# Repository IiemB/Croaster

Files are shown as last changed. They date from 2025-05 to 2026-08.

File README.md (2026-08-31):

# ☕ Croaster - Open Source Coffee Roaster Monitor

> 🇮🇩 Versi Bahasa Indonesia tersedia di [README_ID.md](README_ID.md)

**Croaster** is a lightweight, open-source temperature monitoring system built on ESP-based microcontrollers. Designed for coffee roasting enthusiasts and professionals, it reads from two thermocouple sensors (Bean Temperature and Environment Temperature) and displays real-time data on a compact OLED screen. Croaster connects seamlessly to popular roasting software via WiFi (WebSocket) and BLE (on boards that support it), making it compatible with both desktop and mobile roasting apps.

**Current Firmware Version:** `0.52`

---

## 📑 Table of Contents

- [☕ Croaster - Open Source Coffee Roaster Monitor](#-croaster---open-source-coffee-roaster-monitor)
  - [📑 Table of Contents](#-table-of-contents)
  - [🚀 Features](#-features)
  - [🧩 Hardware Components](#-hardware-components)
  - [🛠 Software Architecture](#-software-architecture)
    - [Data Flow](#data-flow)
  - [📦 Libraries \& Dependencies](#-libraries--dependencies)
  - [🔧 How to Build and Upload](#-how-to-build-and-upload)
  - [📦 Using Croaster as a library in your own project](#-using-croaster-as-a-library-in-your-own-project)
  - [🔗 WiFi Setup Guide](#-wifi-setup-guide)
  - [📡 Communication Overview](#-communication-overview)
    - [WebSocket (WiFi)](#websocket-wifi)
    - [BLE](#ble)
  - [🔌 How to Connect Croaster with Artisan](#-how-to-connect-croaster-with-artisan)
    - [🖥️ Option 1: Direct Connection (Croaster as Access Point)](#️-option-1-direct-connection-croaster-as-access-point)
    - [🌐 Option 2: Same WiFi Network (Croaster joins your WiFi)](#-option-2-same-wifi-network-croaster-joins-your-wifi)
  - [⬆️ OTA (Over-The-Air) Updates](#️-ota-over-the-air-updates)
  - [🧪 Custom Commands](#-custom-commands)
    - [Built-in Commands](#built-in-commands)
    - [Adding Custom Commands](#adding-custom-commands)
  - [📘 License](#-license)
  - [❤️ Contributing](#️-contributing)
  - [🔗 Related Links](#-related-links)

---

## 🚀 Features

* Supports **ESP8266 and ESP32** based boards via per-board implementations
* Real-time monitoring of **two MAX6675 thermocouple sensors**:
  - **BT** — Bean Temperature (inside the drum)
  - **ET** — Environment Temperature (exhaust/inlet)
* **Rate of Rise (RoR)** calculation for both BT and ET, updated automatically
* Temperature unit switching: **Celsius** or **Fahrenheit**
* Configurable data send interval (default: every **3 seconds**)
* Built-in **temperature smoothing** (smoothing factor: 5) to reduce sensor noise
* Visual output on a **128×64 OLED display** (SSD1306, I2C)
* WiFi communication via **WebSocket** on port **81**, compatible with:
  + [**Artisan Roaster Scope**](https://artisan-scope.org/) — industry-standard roasting logger
  + [**ICRM app**](https://iiemb.github.io/#/icrm) — companion mobile app (Android)
* **BLE communication** (on boards that support it) for the [**ICRM app**](https://iiemb.github.io/#/icrm)
* **OTA (Over-The-Air) firmware updates** via WebSocket (WiFi) and **BLE** (on boards that support it)
* **WiFiManager** captive portal for easy WiFi credential setup — no re-flashing needed
* Unique device naming based on chip ID (e.g. `Croaster-A1B2`)
* **Dummy mode** for development and testing without physical sensors
* Custom JSON command system via the centralized `CroasterCommandHandler` class
* Easily extendable with user-defined commands

---

## 🧩 Hardware Components

| Component | Description |
|:---|:---|
| 1× ESP-based microcontroller (WiFi and/or BLE) | Main microcontroller — see `boards/<board>/README.md` for the supported boards |
| 1× [128×64 OLED display (SSD1306, I2C)](images/OLED-Display.png) | Real-time temperature display |
| 2× [MAX6675 thermocouple modules](images/MAX6675.png) | SPI-based K-type thermocouple ADC |
| 2× [K-type thermocouple probes](images/Type-K-thermocouple.png) | Temperature probes (BT & ET) |

> All components run on **3.3V**. Ensure your power supply can handle the combined current draw of both sensors and the display.

> 🔌 **Wiring diagrams are per board** — see `boards/<board>/README.md`.

---

## 🛠 Software Architecture

Croaster uses a clean, **modular C++ architecture** built with the Arduino framework. Each subsystem is encapsulated in its own class.

The repository is structured as a **reusable library** (`croaster/`: `croaster/src/` + `croaster/library.json`) plus per-board **projects** in `boards/<board>/`. The library is **display- and pin-config-agnostic** — each board supplies its own display, pin layout, LED and dummy-mode configuration.

### Library modules (`croaster/src/`)

| Module | File | Responsibility |
|:---|:---|:---|
| `CroasterCore` | `croaster/src/CroasterCore.h/.cpp` | Sensor reading, RoR calculation, temperature smoothing, data state |
| `CroasterDisplay` | `croaster/src/CroasterDisplay.h` | **Abstract display interface** — implemented by the consuming project |
| `CroasterPinConfig` | `croaster/src/CroasterPinConfig.h` | Thermocouple pin layout (passed to `CroasterCore`) |
| `CroasterCommandHandler` | `croaster/src/CroasterCommandHandler.h/.cpp` | JSON command parsing and dispatching (BLE & WebSocket) |
| `CroasterWebSocketManager` | `croaster/src/CroasterWebSocketManager.h/.cpp` | WebSocket server, data broadcast, OTA trigger |
| `CroasterBleManager` | `croaster/src/CroasterBleManager.h/.cpp` | BLE server, characteristic notify, command receive *(only compiled when the board has BLE)* |
| `CroasterOtaHandler` | `croaster/src/CroasterOtaHandler.h/.cpp` | Binary OTA update handling over WebSocket and BLE |
| `CroasterWiFiManager` | `croaster/src/CroasterWiFiManager.h/.cpp` | WiFiManager captive portal setup and lifecycle |
| `CroasterDeviceIdentity` | `croaster/src/CroasterDeviceIdentity.h/.cpp` | Chip ID, device name, IP address helpers |
| `CroasterApp` | `croaster/src/CroasterApp.h/.cpp` | **Single `begin()`/`loop()` entry point** — display-agnostic; takes `CroasterCore&` + `CroasterDisplay*` (+ LED pin/level) |

### Board projects (`boards/`)

Shared components and per-board projects live under `boards/`:

| Path | Purpose |
|:---|:---|
| `boards/common/` | Shared SSD1306 display + animation (`CroasterDisplaySSD1306`, `CroasterDisplayAnimation`) used by the OLED-based boards |
| `boards/<board>/` | Per-board project: `platformio.ini`, `main.cpp`, `config.h`, plus a `README.md` documenting that board (wiring, build flags, partitions) |

Each board folder is a standalone PlatformIO project (`main.cpp` + `config.h`) that consumes the Croaster library (`../../croaster`) and any shared components (`../common`), then wires them into the library's display-agnostic `CroasterApp`.

### Data Flow

```
MAX6675 Sensors → CroasterCore (read + smooth + RoR)
                       ↓
          ┌────────────┴────────────┐
  CroasterWebSocketManager  CroasterBleManager (boards with BLE)
          ↓                         ↓
   Artisan / ICRM              ICRM (Android)
```

---

## 📦 Libraries & Dependencies

| Library | Purpose |
|:---|:---|
| [arduinoWebSockets](https://github.com/Links2004/arduinoWebSockets) | WebSocket server |
| [ArduinoJson](https://arduinojson.org/) `^7.4.3` | JSON command parsing and serialization |
| [Adafruit SSD1306](https://github.com/adafruit/Adafruit_SSD1306) `^2.5.16` | OLED display driver |
| [MAX6675_Thermocouple](https://github.com/YuriiSalimov/MAX6675_Thermocouple) `^2.0.2` | Thermocouple sensor reading |
| [WiFiManager](https://github.com/tzapu/WiFiManager) `^2.0.17` | Captive portal WiFi setup |
| ESP32 BLE Arduino *(built-in ESP32 core)* | BLE server & characteristics |

---

## 🔧 How to Build and Upload

> PlatformIO is the only supported workflow (Arduino IDE is not used).

The library lives in `croaster/`. Each supported board has its own folder under
`boards/` — pick it and build/upload from there:

1. Install [PlatformIO](https://platformio.org/) (VS Code extension or CLI)
2. Clone the repository and enter your board's folder:

   ```bash
   git clone git@github.com:IiemB/Croaster.git
   cd Croaster/boards/<board>
   ```

3. Review `platformio.ini` and select your target environment
4. Upload the firmware:

   ```bash
   pio run -t upload
   ```

Each board's `README.md` documents its own build command, wiring and any special
build flags (e.g. custom partition tables).

---

## 📦 Using Croaster as a library in your own project

`croaster/` is a standard PlatformIO library (it ships its own `library.json`).
Add it to another project's `platformio.ini`:

```ini
[env:your_board]
lib_deps =
    https://github.com/IiemB/Croaster.git
```

The easiest way to start is to copy a board (`boards/<board>/`) and adapt it.
It exposes a single `begin()`/`loop()`
API via `CroasterApp`, and all board-specific config (pins, dummy mode, LED,
display) lives in the implementation — not the library:

```cpp
#include <Arduino.h>
#include <ArduinoJson.h>
#include "config.h"                 // pins, dummyMode, ledPin/ledOnLevel (edit here)
#include "CroasterDisplaySSD1306.h" // or your own CroasterDisplay subclass
#include "CroasterApp.h"

CroasterCore core(dummyMode, pins);
CroasterDisplaySSD1306 display(core);     // display defined in the implementation
CroasterApp app(core, &display, ledPin, ledOnLevel);

void setup() { app.begin(); }
void loop()  { app.loop(); }
```

Or wire it yourself (see `CroasterApp.cpp` for the full wiring):

```cpp
#include <CroasterCore.h>
#include <CroasterPinConfig.h>
#include <CroasterCommandHandler.h>
#include <CroasterWebSocketManager.h>
#include <CroasterBleManager.h>
#include <CroasterWiFiManager.h>

CroasterPinConfig myPins = { /* sckPin, soPin, csPinBt, csPinEt */ };

CroasterCore croaster(false, myPins);   // your pin layout
MyDisplay display(croaster);            // your CroasterDisplay subclass
CroasterCommandHandler commands(croaster, &display);
CroasterWebSocketManager ws(croaster, commands, &display);

#if CROASTER_HAS_BLE  // auto-detected: 1 on ESP32, 0 otherwise
CroasterBleManager ble(croaster, commands, &display);
#endif
```

- **Display** — implement `CroasterDisplay` (`begin`, `loop`, `rotateScreen`,
  `blinkIndicator`, `displayToggle`, and the OTA-progress methods). Pass
  `nullptr` where the board has no display.
- **Pins, dummy mode & LED** — build your own `CroasterPinConfig` and pass it
  to `CroasterCore`; choose `dummyMode`, `ledPin`/`ledOnLevel` in the
  implementation's `config.h`.
- **BLE** — the library detects BLE support at compile time via
  `CROASTER_HAS_BLE` (1 on ESP32, 0 elsewhere) and only compiles
  `CroasterBleManager` when available.
- **Custom commands** — add commands without touching the library:
  `app.commands().onCommand("ping", ...)` for string commands and
  `app.commands().onJsonCommand("myKey", ...)` for nested JSON commands.

---

## 🔗 WiFi Setup Guide

Croaster uses **WiFiManager** to handle WiFi credentials without re-flashing. On first boot (or after erasing credentials), Croaster creates its own access point:

1. On your phone or computer, connect to the WiFi network named `[XXXX] Croaster-XXXX`
2. A captive portal will open automatically — enter your home WiFi SSID and password
3. Croaster will save the credentials and connect automatically on subsequent boots
4. The IP address assigned to Croaster is shown on the OLED display

For a visual walkthrough, see: ➡️ [How to Connect to WiFi - YouTube](https://www.youtube.com/watch?v=esNiudoCEcU&t=434s)

---

## 📡 Communication Overview

### WebSocket (WiFi)

- **Port:** `81`
- **Protocol:** WebSocket (text frames for JSON commands, binary frames for OTA)
- **Data format:** JSON, broadcast every `intervalSend` seconds (default: 3s)
- Compatible with **Artisan Roaster Scope** and **ICRM app** (Android)

### BLE

- **Service UUID:** `1cc9b045-a6e9-4bd5-b874-07d4f2d57843`
- **Data Characteristic UUID:** `d56d0059-ad65-43f3-b971-431d48f89a69`
- Supports notify (data push) and write (command receive)
- Available on boards that support BLE (e.g. ESP32) — compatible with the **ICRM app** (Android)

---

## 🔌 How to Connect Croaster with Artisan

You can connect your Croaster device to Artisan using either a direct WiFi connection or through your home/local WiFi network.

1. Open Artisan → **Config → Device**
2. Select **Meter → WebSocket**
   
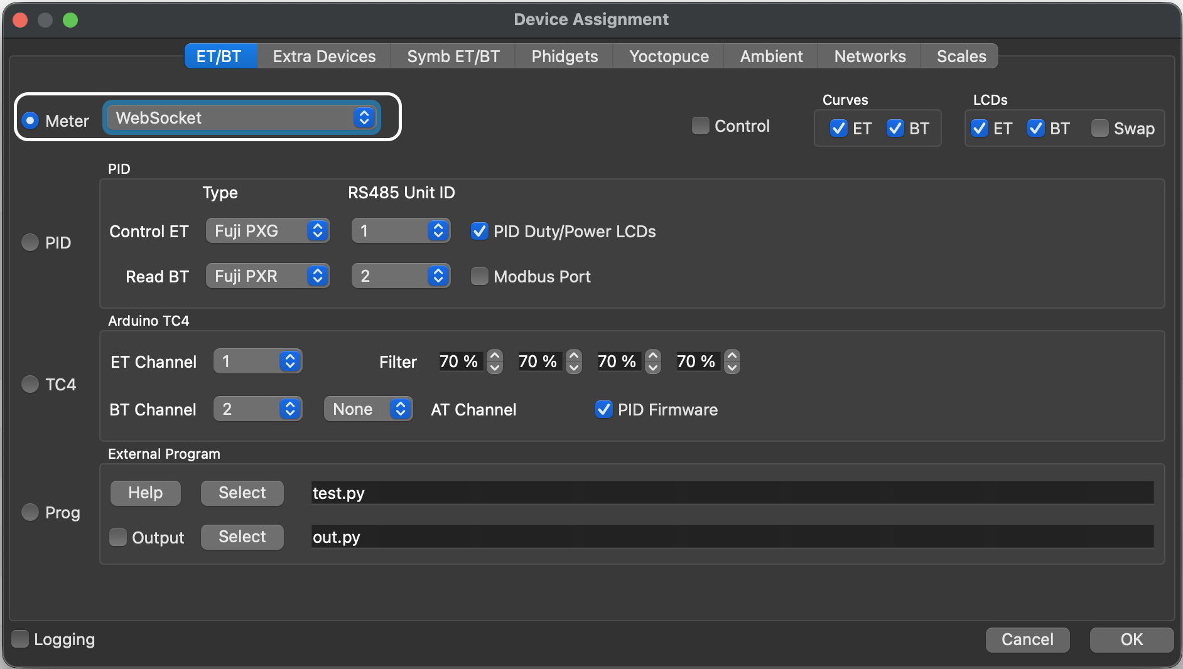
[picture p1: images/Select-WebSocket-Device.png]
   

### 🖥️ Option 1: Direct Connection (Croaster as Access Point)

Use this method when Croaster is **not** connected to any WiFi network, or when you want a direct peer-to-peer connection.

1. On your computer, connect to the WiFi network broadcasted by Croaster (e.g. `[XXXX] Croaster-XXXX`)
2. Open Artisan → **Config → Port**
3. Set the configuration as shown below:

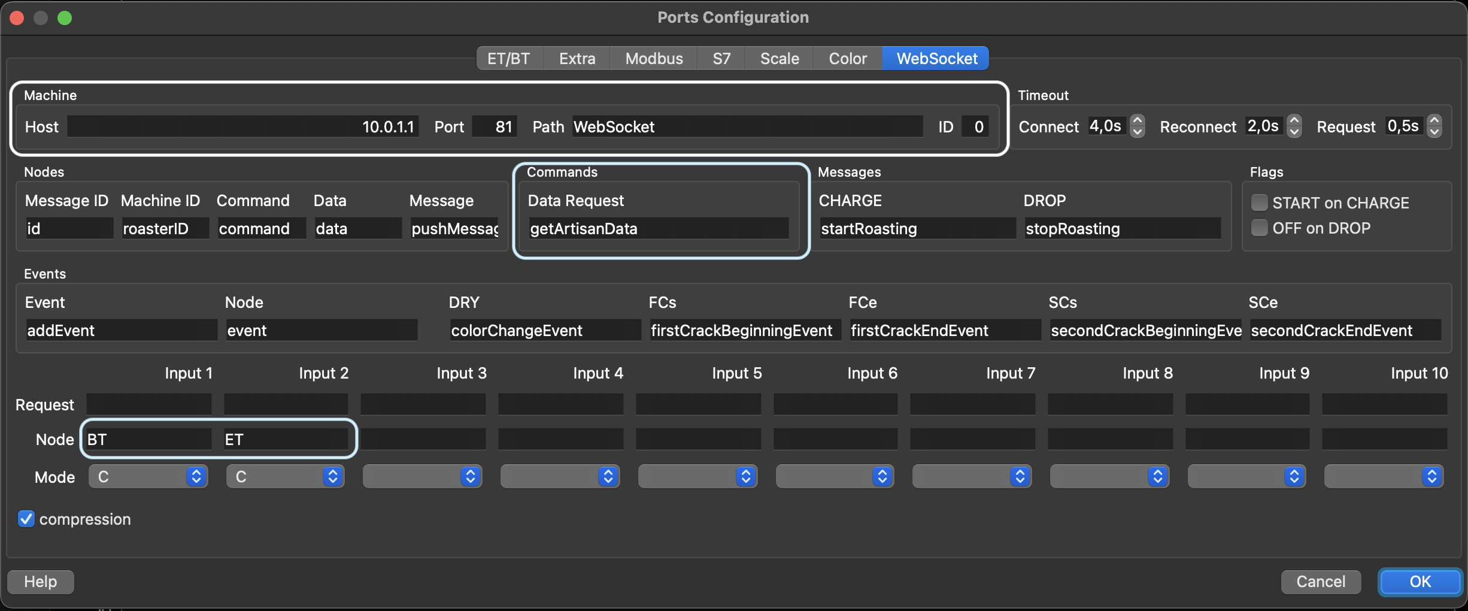
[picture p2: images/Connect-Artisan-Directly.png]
   

### 🌐 Option 2: Same WiFi Network (Croaster joins your WiFi)

Use this method when Croaster is already connected to your home/office WiFi network.

1. Make sure your laptop and Croaster are on the **same WiFi network**
2. Open Artisan → **Config → Port**
3. Enter the **IP address** shown on the Croaster OLED display (or via serial monitor)
4. Set the configuration as shown:

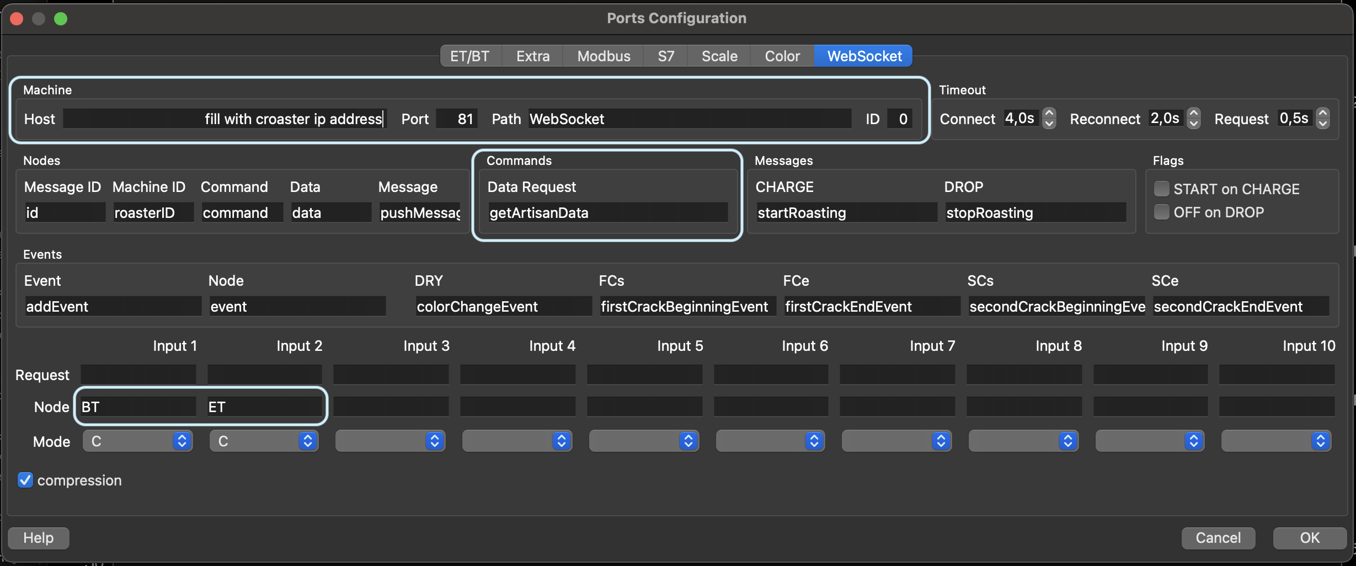
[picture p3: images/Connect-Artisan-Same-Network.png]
   

---

## ⬆️ OTA (Over-The-Air) Updates

Croaster supports firmware updates without a USB cable, via the **ICRM app** over WebSocket (WiFi) or BLE (on boards that support it).

- OTA is handled by the `CroasterOtaHandler` class, which receives binary firmware data in chunks and returns a JSON progress payload after each chunk
- Progress is shown on the OLED display during the update
- BLE OTA includes timeout checks to handle stalled transfers
- Some boards need a partition table with an OTA slot — see the board's `README.md`
- After a successful OTA update, Croaster restarts automatically

---

## 🧪 Custom Commands

Croaster accepts JSON-formatted commands over both WebSocket and BLE. The `CroasterCommandHandler` class dispatches all incoming commands.

### Built-in Commands

All commands use the `"command"` key. Basic (string) commands:

| Command JSON | Action |
|:---|:---|
| `{"command": "restartesp"}` | Restarts the device |
| `{"command": "erase"}` | Erases WiFi credentials and restarts |
| `{"command": "displayToggle"}` | Toggles the OLED display on/off |
| `{"command": "rotateScreen"}` | Rotates the OLED screen 180° |
| `{"command": "dummyToggle"}` | Toggles dummy/test mode on or off |
| `{"command": "blink"}` | Blinks the built-in LED |
| `{"command": "getDeviceInfo"}` | Returns device info (IP, SSID, firmware version) |
| `{"command": "getExtra"}` | Returns extra user-defined data |

Configuration commands use a **nested JSON object** under `"command"`:

| Command JSON | Action |
|:---|:---|
| `{"command": {"tempUnit": "F"}}` | Switches temperature unit to Fahrenheit |
| `{"command": {"tempUnit": "C"}}` | Switches temperature unit to Celsius |
| `{"command": {"interval": 5}}` | Sets data send interval to 5 seconds |
| `{"command": {"correctionBt": 1.5, "correctionEt": -0.5}}` | Applies temperature correction offset |
| `{"command": {"wifiConnect": {"ssid": "MyWiFi", "pass": "password"}}}` | Connects to a specified WiFi network |

### Adding Custom Commands

Custom commands are registered in your implementation's `main.cpp` — **no library
edits needed**:

```cpp
app.commands().onCommand("ping", [](const JsonObject &json) -> String { ... });
app.commands().onJsonCommand("myKey", [](const JsonObject &json) -> String { ... });
```

`onCommand` handles basic string commands (`{"command":"ping"}`); `onJsonCommand`
handles nested JSON keys (`{"command":{"myKey":...}}`). Each callback returns a
response string (empty = no response). Both are available over WebSocket and BLE.

---

## 📘 License

[MIT License](LICENSE.md) — free for personal and commercial use. Contributions welcome!

---

## ❤️ Contributing

Pull requests, bug reports, and feature requests are welcome! Feel free to open an issue or submit a PR on [GitHub](https://github.com/IiemB/Croaster).

---

## 🔗 Related Links

- [ICRM App](https://iiemb.github.io/#/icrm) — companion Android app for Croaster
- [Artisan Roaster Scope](https://artisan-scope.org/) — open-source coffee roasting logger
- [WiFi Setup Video](https://www.youtube.com/watch?v=esNiudoCEcU&t=434s) — quick visual guide
- [FAQ](FAQ.md) — frequently asked questions

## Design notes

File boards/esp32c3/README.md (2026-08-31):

# Croaster — ESP32-C3 Super Mini Implementation

This folder is a standalone **PlatformIO** project for the **ESP32-C3 Super Mini**
board. It consumes the Croaster library from `croaster/` (`../../croaster`)
plus the shared SSD1306 display (`../common`), and wires them into the
library's display-agnostic `CroasterApp` (`src/main.cpp`).

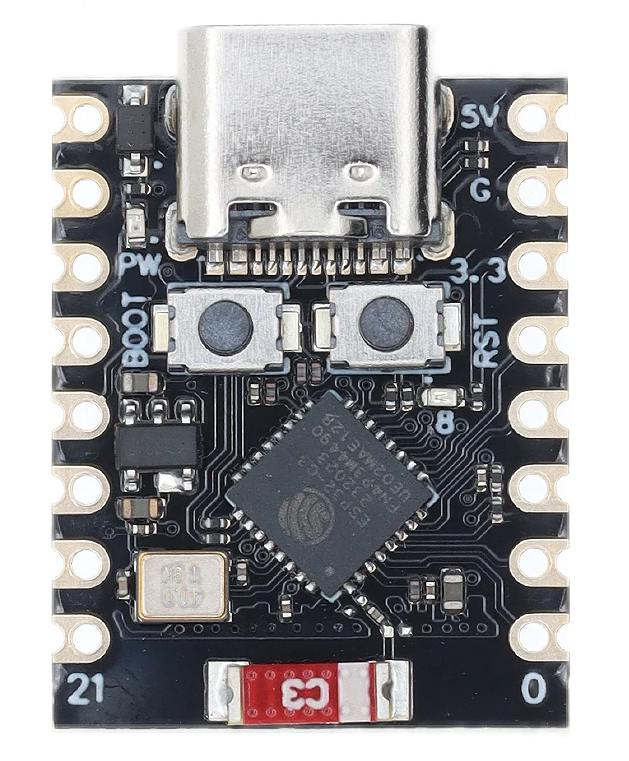
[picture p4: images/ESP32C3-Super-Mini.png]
ESP32-C3 Super Mini


---

## 📋 Board

- **MCU:** ESP32-C3 (RISC-V), **WiFi + BLE**
- **Display:** 128×64 SSD1306 OLED (I2C) — from `boards/common`
- **Partition scheme:** custom `custom32c3sm.csv` (in this folder) — a 1.9 MB
  app slot **with an OTA slot**, set via `board_build.partitions = custom32c3sm.csv`

---

## 🔧 Build & Upload

```bash
cd boards/esp32c3
pio run -e esp32c3 -t upload
```

> BLE is compiled in automatically — `CroasterBleManager` is only built when the
> board has BLE (`CROASTER_HAS_BLE`).

---

## 🔌 Wiring

| Component | GPIO |
|:---|:---:|
| **OLED** SCL | 9 |
| **OLED** SDA | 8 |
| **ET sensor** SCK | 4 |
| **ET sensor** SO | 5 |
| **ET sensor** CS | 6 |
| **BT sensor** SCK | 4 |
| **BT sensor** SO | 5 |
| **BT sensor** CS | 7 |

Both sensors share the **SCK** and **SO** lines (SPI bus); they are distinguished
by their individual **CS** pins. All components run on **3.3V**.

---

## ⚙️ Configuration (`src/config.h`)

| Setting | Default | Purpose |
|:---|:---|:---|
| `dummyMode` | `false` | Dummy sensor data (no real thermocouples needed) |
| `pins` | `{4, 5, 7, 6}` | Thermocouple layout: SCK=4, SO=5, CS_BT=7, CS_ET=6 |
| `ledPin` | `LED_BUILTIN` | Built-in LED pin (`-1` disables the blink command) |
| `ledOnLevel` | `LOW` | Active level of the built-in LED |

---

## ⬆️ OTA

OTA is supported over **WebSocket (WiFi)** and **BLE**. It requires the custom
`custom32c3sm` partition (set in `platformio.ini`), which reserves an OTA slot —
the default 4 MB `Huge APP`-style schemes do **not** support OTA.

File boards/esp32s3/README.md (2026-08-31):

# Croaster — ESP32-S3 Implementation (board: ES3C28P)

This folder is a standalone **PlatformIO** project for the **ES3C28P** board
(ESP32-S3 2.8" ILI9341 LCD). It consumes the Croaster library from
`croaster/` (`../../croaster`) and implements the **LVGL** UI on the built-in
IPS LCD, wired
into the library's display-agnostic `CroasterApp` (`src/main.cpp`).

---

## 📋 Board

- **MCU:** ESP32-S3 (dual-core Xtensa LX7), **WiFi + BLE**
- **Flash:** 16 MB · **PSRAM:** 8 MB (OPI PSRAM with DIO flash)
- **Display:** ILI9341 240×320 SPI TFT — landscape 320×240 (LVGL 9)
- **Touch:** FT6336G capacitive I2C
- **Partition scheme:** `default_16MB.csv`

---

## 🔧 Build & Upload

```bash
cd boards/esp32s3
pio run -e esp32s3 -t upload
```

Or build every board and collect the firmware with `./build_all.sh` (outputs
land in the gitignored `builds/` folder).

> BLE is compiled in automatically — `CroasterBleManager` is only built when the
> board has BLE (`CROASTER_HAS_BLE`).
>
> ESP-IDF Kconfig overrides (`esp32s3-sdkconfig.defaults`) fix
> `MBEDTLS_ERR_SSL_ALLOC_FAILED` on WSS connect and tune the NimBLE stack — see
> the file for full explanations.

---

## 📺 UI

Instrument-style LVGL dashboard (landscape 320×240):

- top bar with brand/IP and WiFi/BLE status chips
- BT/ET temperature cards with RoR
- bottom bar: roast timer + a single **START → STOP → RESET** control button
- swipe left for a rolling BT/ET roast-profile chart, swipe right to return
- double-tap toggles the backlight (LEDC PWM on IO45); light/dark theme

The roast timer lives in the Croaster library core (`CroasterCore`:
`roastTimerStart/Pause/Reset`) and is surfaced by the UI and the
`getDeviceInfo` JSON command. Custom WebSocket/BLE commands registered in
`src/main.cpp` control the backlight (`brightness`) and theme (`darkMode`).

---

## 🔌 Wiring

| Component | GPIO |
|:---|:---:|
| **ILI9341** CS | 10 |
| **ILI9341** DC | 46 |
| **ILI9341** SCK | 12 |
| **ILI9341** MOSI | 11 |
| **ILI9341** MISO | 13 |
| **ILI9341** RST | −1 (tied to board reset) |
| **Backlight** BL | 45 (LEDC PWM) |
| **FT6336G** SDA | 16 |
| **FT6336G** SCL | 15 |
| **FT6336G** RST | 18 |
| **FT6336G** INT | 17 |
| **ET sensor** SCK | 2 |
| **ET sensor** SO | 3 |
| **ET sensor** CS | 21 |
| **BT sensor** SCK | 2 |
| **BT sensor** SO | 3 |
| **BT sensor** CS | 14 |

Both thermocouples share the **SCK** and **SO** lines (SPI bus); they are
distinguished by their individual **CS** pins. All components run on **3.3V**.

---

## ⚙️ Configuration

| File | Purpose |
|:---|:---|
| `src/config.h` | Dummy mode, thermocouple pins (`pins = {2, 3, 14, 21}`), LED |
| `src/pins.h` | LCD + touch pin layout (used by `LvglUi` / `LvglTouch`) |
| `src/ui/` | LVGL UI (`LvglUi.*`), touch (`LvglTouch.*`) and `lv_conf.h` |
| `platformio.ini` | Env `esp32s3`; board id `CroasterDeviceIdentity::setBoardName("esp32s3")` in `src/main.cpp` |
| `esp32s3-sdkconfig.defaults` | ESP-IDF Kconfig overrides (mbedTLS, NimBLE) |

---

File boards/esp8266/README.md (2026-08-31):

# Croaster — ESP8266 (NodeMCU / ESP-12E) Implementation

This folder is a standalone **PlatformIO** project for the **NodeMCU / ESP-12E**
board. It consumes the Croaster library from `croaster/` (`../../croaster`)
plus the shared SSD1306 display (`../common`), and wires them into the
library's display-agnostic `CroasterApp` (`src/main.cpp`).

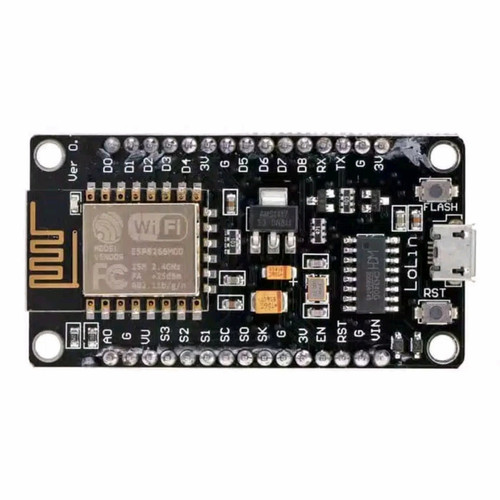
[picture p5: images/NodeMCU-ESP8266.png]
NodeMCU ESP8266


---

## 📋 Board

- **MCU:** ESP8266, **WiFi only** (no BLE)
- **Display:** 128×64 SSD1306 OLED (I2C) — from `boards/common`
- **Partition scheme:** the default NodeMCU layout (includes an OTA slot)

---

## 🔧 Build & Upload

```bash
cd boards/esp8266
pio run -e esp8266 -t upload
```

> BLE is not compiled on this board — `CroasterBleManager` is excluded
> automatically (`CROASTER_HAS_BLE` is 0 on ESP8266).

---

## 🔌 Wiring

| Component | NodeMCU pin |
|:---|:---:|
| **OLED** SCL | D1 |
| **OLED** SDA | D2 |
| **ET sensor** SCK | D5 |
| **ET sensor** SO | D7 |
| **ET sensor** CS | D6 |
| **BT sensor** SCK | D5 |
| **BT sensor** SO | D7 |
| **BT sensor** CS | D8 |

Both sensors share the **SCK** and **SO** lines (SPI bus); they are distinguished
by their individual **CS** pins. All components run on **3.3V**.

---

## ⚙️ Configuration (`src/config.h`)

| Setting | Default | Purpose |
|:---|:---|:---|
| `dummyMode` | `false` | Dummy sensor data (no real thermocouples needed) |
| `pins` | `{D5, D7, D8, D6}` | Thermocouple layout: SCK=D5, SO=D7, CS_BT=D8, CS_ET=D6 |
| `ledPin` | `LED_BUILTIN` | Built-in LED pin (`-1` disables the blink command) |
| `ledOnLevel` | `LOW` | Active level of the built-in LED |

---

## ⬆️ OTA

OTA is supported over **WebSocket (WiFi)** using the default NodeMCU partition
scheme (which includes an OTA slot). BLE OTA is not available on the ESP8266.

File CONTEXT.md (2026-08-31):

# CONTEXT.md — Croaster firmware (current state)

## What this repo is
The **Croaster** coffee-roaster firmware, structured as a reusable
display/pin-agnostic library (`croaster/`) plus standalone per-board PlatformIO
projects (`boards/<board>/`). It is a git submodule of the ICRM
Flutter app (remote `git@github.com:IiemB/Croaster.git`) and is consumed via
`lib_deps = https://github.com/IiemB/Croaster.git`.

## Repo layout
| Path | Purpose |
|:---|:---|
| `croaster/src/` | Library core: `CroasterCore`, `CroasterDisplay` (interface), `CroasterApp` (begin()/loop()), `CroasterCommandHandler`, `CroasterBleManager`, `CroasterWebSocketManager`, `CroasterOtaHandler`, `CroasterWiFiManager`, `CroasterDeviceIdentity`, `CroasterPinConfig`, `CroasterConstants` |
| `boards/common/` | Shared SSD1306 display + animation (small lib, added via `../common`) |
| `boards/esp32c3/` | ESP32-C3 Super Mini — SSD1306 OLED; custom OTA partition (`custom32c3sm.csv` lives in this folder) |
| `boards/esp8266/` | NodeMCU / ESP-12E — SSD1306 OLED |
| `boards/esp32s3/` | ES3C28P 2.8" ILI9341 LCD — LVGL 9 UI + FT6336G touch (`src/ui/`) |
| `builds/` | gitignored firmware output of `./build_all.sh` |

## Boards
| Board | MCU | Display | Env | Flash (build_all) |
|:---|:---|:---|:---|:---|
| `esp32c3` | ESP32-C3 | 128×64 SSD1306 | `esp32c3` | ~85.7% |
| `esp8266` | ESP8266 | 128×64 SSD1306 | `esp8266` | ~39.8% |
| `esp32s3` (ES3C28P) | ESP32-S3 | 320×240 ILI9341 + LVGL 9 | `esp32s3` | ~29.0% |

## How a board is wired
- `main.cpp` creates `CroasterCore core(dummyMode, pins)`, a display subclass
  (e.g. `CroasterDisplaySSD1306` / `CroasterDisplayS3`), and
  `CroasterApp app(core, &display, ledPin, ledOnLevel)`, then calls
  `app.begin()` / `app.loop()`.
- Board id is hardcoded per board via
  `CroasterDeviceIdentity::setBoardName("esp32s3")` in its `main.cpp`, read
  by `CroasterDeviceIdentity::boardName()` (no compile-time board guards;
  defaults to `unknown` until set).
- Builds: `build_all.sh` builds only the **release** env of each board
  (`build_type = release`; `pio run -e <board>`); `./upload_monitor.sh <board>`
  builds + uploads the **debug** variant (`<board>-debug`, `extends` the
  release env) to the connected board, then opens the serial monitor.
- Library features added in 0.52: roast timer (`CroasterCore::roastTimerStart/
  Pause/Reset`), `getDeviceInfo` now reports `board`/`darkMode`/`brightness`
  (display state via `CroasterDisplay::isDarkMode()/getBrightness()`), and a
  BLE-guarded `CroasterApp::ble()` accessor.

## Git state (2026-08-30)
- Branch `dev` (HEAD `3f52109`, tracks `origin/dev`); the `boards/` + `croaster/`
  restructure, per-board `setBoardName()`, and the 0.62 bump are committed
  (merged from `decoupling` via PR #31). Working tree **clean** after this batch.
- The ESP32-S3 LVGL implementation was ported from the old single-project
  `ES3C28P` branch into `boards/esp32s3/`
  (`git show ES3C28P:<path>` is the source of the UI).
- `build_all.sh` emits `builds/Croaster_<board>_<version>.bin` (version read
  from `croaster/src/CroasterConstants.h`).
- This batch adds `format.sh` + `.clang-format` (all sources reformatted) and
  the esp32s3 `darkMode` / `brightness` custom commands.
- ⚠️ **Downstream:** the ICRM app consumes this repo via
  `lib_deps = https://github.com/IiemB/Croaster.git`, which needs `library.json`
  at the repo root — update it to the `croaster/` subfolder (or add a root
  `library.json`).

## Next steps
- Update the ICRM app's `lib_deps` for the `croaster/` subfolder.
- Flash + verify the esp32s3 build on real hardware (touch, chart swipe,
  dark mode, OTA over BLE/WebSocket).
- Confirm `boardName()` strings against the ICRM app's `CroasterBoardTypes`.

## Gotchas
- PlatformIO not on PATH → `~/.platformio/penv/bin/pio` or `PIO=`.
- Libs are **live-linked** via `symlink://` lib_deps
  (`Croaster=symlink://../../croaster`, `CroasterDisplaySSD1306=symlink://../common`)
  — editing `croaster/src/` needs no `.pio/libdeps` cleanup.
- ESP32-C3: WiFiManager AP can fail to broadcast under the PIO core (2.0.17) —
  fixed via DIO flash mode + `WiFi.setTxPower(WIFI_POWER_18_5dBm)` in the
  configMode callback (see `boards/esp32c3/` notes).
- ESP32-S3 (LVGL): heavy UI work must run on its FreeRTOS task (Core 0), never
  the Arduino loop task; the theme switch is deferred via
  `themeRebuildPending` + `LvglUi::rebuildTheme()` on the LVGL task.
- ESP32-S3: WSS connect needs the mbedTLS PSRAM/buffer Kconfig overrides in
  `boards/esp32s3/esp32s3-sdkconfig.defaults` (otherwise
  `MBEDTLS_ERR_SSL_ALLOC_FAILED`).

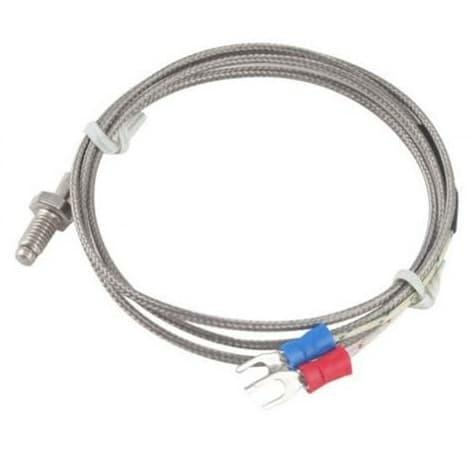
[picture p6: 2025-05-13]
images/Type-K-thermocouple.png

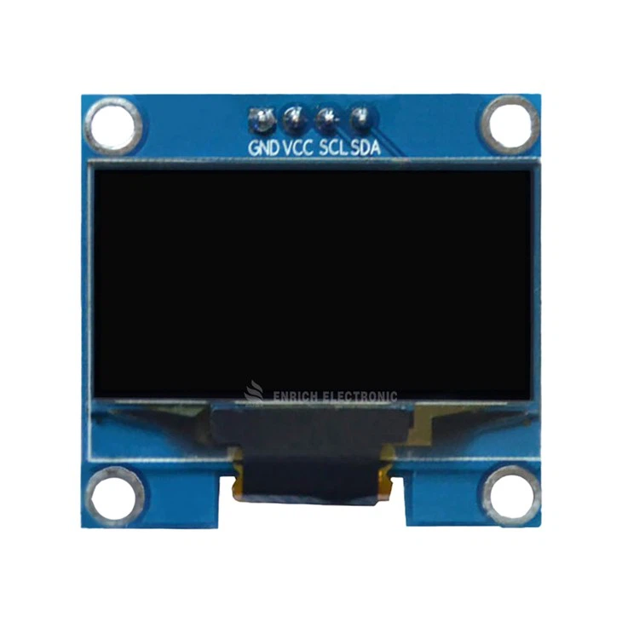
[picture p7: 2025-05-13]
images/OLED-Display.png

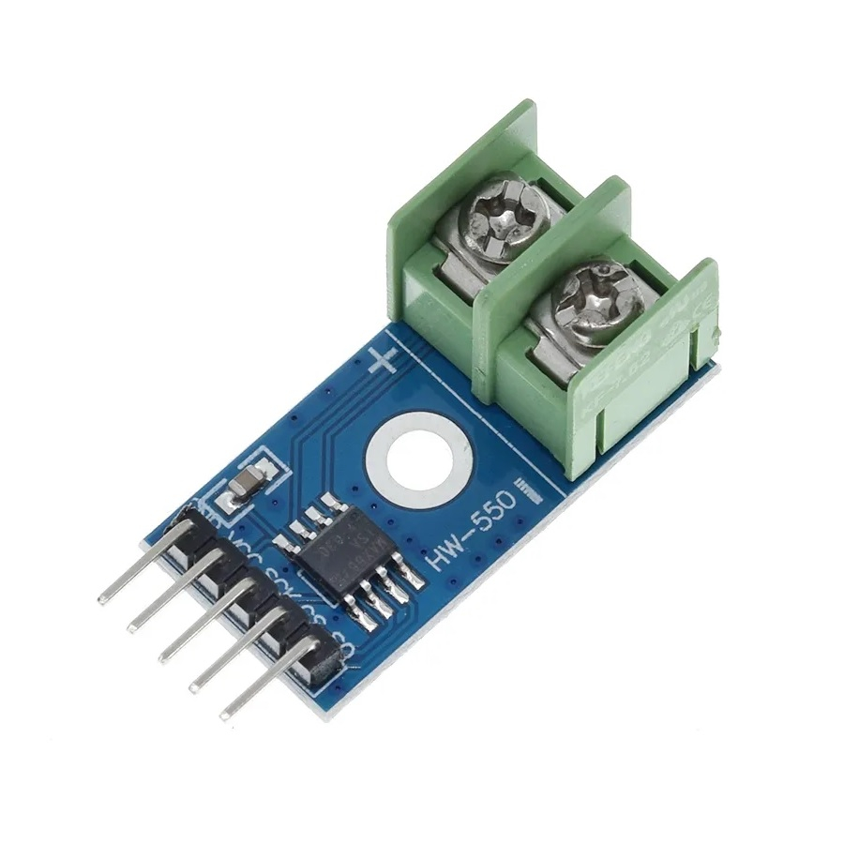
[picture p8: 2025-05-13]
images/MAX6675.png

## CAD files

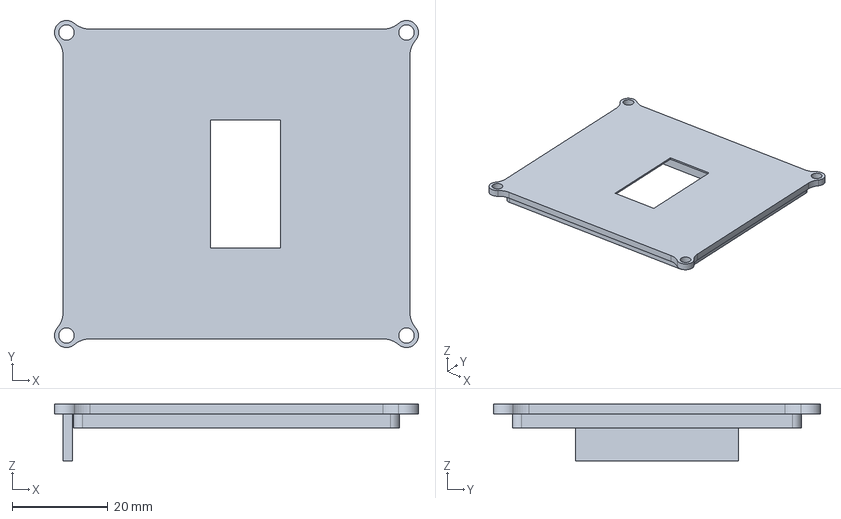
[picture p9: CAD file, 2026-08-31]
Enclosure_V2.FCStd
75.9 x 68.2 x 11.8 mm

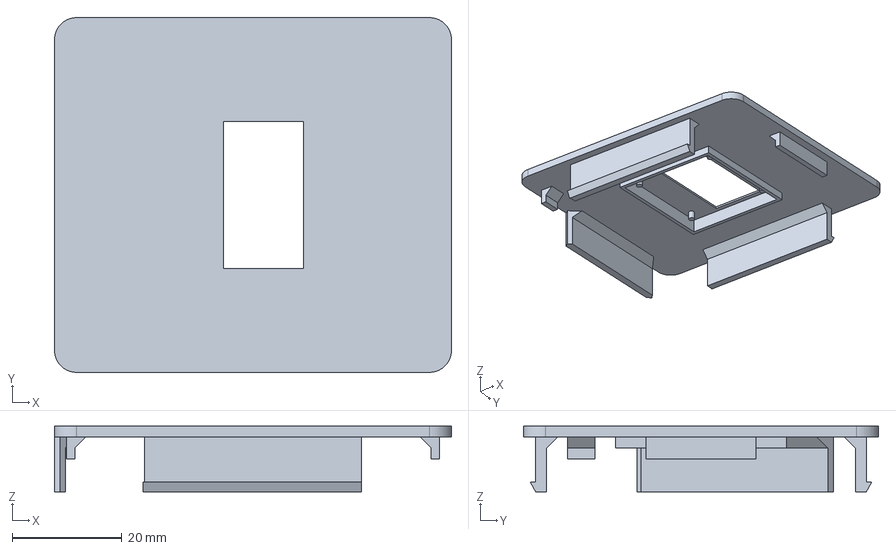
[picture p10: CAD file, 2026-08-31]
Enclosure.FCStd
72.3 x 64.6 x 12.0 mm

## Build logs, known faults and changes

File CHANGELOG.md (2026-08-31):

# Changelog — Croaster Firmware

All notable changes to the Croaster firmware are documented here.  
Format follows [Keep a Changelog](https://keepachangelog.com/en/1.0.0/).

---

## [Unreleased] — 2026-06-13

### Fixed
- Increased the display inversion duration from 5 seconds to 60 seconds

---

## Unreleased

### Added
- **`format.sh`** — run clang-format over the C/C++ sources in `croaster/` and
  `boards/` (`./format.sh` in place, `--check` to verify, `--diff` to preview);
  new root `.clang-format` (Google base, 4-space indent, 120-col limit)
- **ESP32-S3 display commands** — `boards/esp32s3` now handles
  `{"command":{"darkMode":…}}` and `{"command":{"brightness":…}}` over
  WebSocket / BLE, driving `CroasterDisplayS3::setDarkMode()/setBrightness()`

### Changed
- **Reformatted all sources** to the new `.clang-format` (library + boards,
  including the LVGL UI)

## [0.62] — 2026-08-29 (Current)

### Changed
- **`build_all.sh` output naming** — firmware is now collected as
  `builds/Croaster_<board>_<version>.bin` (e.g. `Croaster_esp32s3_0.62.bin`);
  the version is read from `src/CroasterConstants.h` so the filename stays in
  sync with the firmware version
- **Firmware version bumped to `0.62`** — `croaster/src/CroasterConstants.h`,
  `croaster/library.json`, `boards/common/library.json`
- **Board id hardcoded per implementation** — `boardName()` no longer reads a
  `-DCROASTER_BOARD_NAME` build flag; each implementation calls
  `CroasterDeviceIdentity::setBoardName("esp32s3")` in its `main.cpp`
  (defaults to `unknown` until set)
- **Release/debug build split** — each board env is pinned to
  `build_type = release` (so `build_all.sh` always produces release firmware)
  and gains a `<board>-debug` variant (`extends`) used by the new
  `./upload_monitor.sh <board>` script to build + upload debug firmware to a connected
  board
- **Repo restructure** — the library moved to `croaster/` (`library.json`,
  `src/`, `test/`) and per-board projects to `boards/<board>/` (was
  `implementation/<board>/`); boards now consume the library via
  `lib_deps = ../../croaster`

---

## [0.52] — 2026-08-29

### Added
- **Repository is now a reusable library** (`library.json` at the repo root) — another project can consume it via `lib_deps = https://github.com/IiemB/Croaster.git`
- **`examples/` renamed to `implementation/<board>/`** — per-board implementations (`implementation/esp32c3/`, `implementation/esp8266/`), each consuming the library from `../..` exactly like an external project
- **`implementation/esp32s3/`** — ESP32-S3 (ES3C28P) 2.8" ILI9341 LCD board
  (LVGL 9 UI + FT6336G touch), ported from the `ES3C28P` branch into the
  per-board structure (`CroasterDisplayS3` wrapping the LVGL UI in `src/ui/`;
  `esp32s3-sdkconfig.defaults` for mbedTLS/NimBLE Kconfig fixes)
- **Roast timer** in the library core — `CroasterCore::roastTimerStart()/roastTimerPause()/roastTimerReset()` + `roastTimer` (seconds) & `roastTimerIsRunning()`; surfaced by the S3 UI's single START/STOP/RESET button
- **Board + display-state reporting** — `CroasterDeviceIdentity::boardName()` now returns a per-implementation id set via the `-DCROASTER_BOARD_NAME=` build flag (`esp32s3`/`esp32c3`/`esp8266`/`unknown`, no compile-time board guards); `getDeviceInfo` now includes `board`, `darkMode` and `brightness` (via new `CroasterDisplay::isDarkMode()/getBrightness()`); `CroasterApp::ble()` accessor
- **`build_all.sh`** — builds every board implementation and collects the
  firmware into the gitignored `builds/` folder; board-specific
  `CROASTER_ES3C28P` compile-time guards removed from the implementation
  sources (each board builds its own folder unconditionally); `AGENTS.md` and
  `CONTEXT.md` added for the firmware repo
- **Shared SSD1306 display in `implementation/common/`** — both the `esp32c3` and `esp8266` implementations reference the same display/ animation (no duplicated data); the ESP8266 (NodeMCU / ESP-12E) implementation was restored as `implementation/esp8266/`
- **`CroasterDisplay` abstract interface** — the library core is display-agnostic; consuming projects implement their own display (the SSD1306 implementation lives in the reference example as `CroasterDisplaySSD1306`). A `nullptr` display is fully supported (headless boards)
- **`CroasterPinConfig` struct** — pin layout is decoupled from the core and passed to `CroasterCore`; each implementation provides its own pins in `config.h`
- **`CroasterApp` single `begin()`/`loop()` entry point** — lives in the library (`src/CroasterApp.h/.cpp`); the sketch is reduced to `app.begin()` / `app.loop()`
- **`CroasterApp` is display-agnostic** — it takes `CroasterCore&` + `CroasterDisplay*` (+ LED pin/level); the display type is defined in the implementation (`main.cpp`)
- **Custom command registration** — `CroasterCommandHandler::onCommand()` / `onJsonCommand()` let an implementation add commands without touching the library
- **Compile-time BLE detection** via `CROASTER_HAS_BLE` (1 on ESP32, 0 elsewhere) in `CroasterConstants.h` — `CroasterBleManager` is only compiled when the board has BLE
- `SmoothThermocoupleFix.cpp` added to the library (fixes the MAX6675_Thermocouple v2.0.2 link error for all build types)

### Changed
- All classes renamed with the `Croaster` prefix: `BleManager` → `CroasterBleManager`, `CommandHandler` → `CroasterCommandHandler`, `WebSocketManager` → `CroasterWebSocketManager`, `OtaHandler` → `CroasterOtaHandler`, `WiFiManagerUtil` → `CroasterWiFiManager` (class with static methods), `DeviceIdentity` → `CroasterDeviceIdentity`, `DisplayManager` → `CroasterDisplay` (interface) / `CroasterDisplaySSD1306` (reference impl), `DisplayAnimation` → `CroasterDisplayAnimation`
- `Constants.h` → `CroasterConstants.h`, `PinConfig.h` → `CroasterPinConfig.h`
- `LED_ON`/`LED_OFF` macros removed from `CroasterConstants.h`; `CroasterCommandHandler` now takes `ledPin`/`ledOnLevel` per-instance (supplied by the implementation); removed the redundant `-D LED_ON` build flag
- `CroasterApp` moved from the implementation into the library core (`src/CroasterApp.h/.cpp`); registered in `library.json`
- **Arduino IDE support removed** — PlatformIO is the only workflow; deleted `copy_to_ino.sh`, `library.properties`, `setup_custom_partition_macos.sh` and `references.md`
- Removed `CroasterPinConfig::defaults()` — `CroasterCore` now requires an explicit `CroasterPinConfig` (no library pin defaults)
- **Board-specific docs moved to per-board READMEs** (`implementation/<board>/README.md`); the root `README.md`/`README_ID.md` are now board-agnostic (wiring, partitions, board names live in each implementation's README); removed `lib_extra_dirs` from the implementation `platformio.ini` files
- Pin and dummy-mode configuration moved to the implementation (`implementation/esp32c3/src/config.h`); the `dummyMode` global was removed from `CroasterConstants.h`
- Display constants (`SCREEN_WIDTH`/`SCREEN_HEIGHT`/`OLED_RESET`) moved to `CroasterDisplaySSD1306.h`; LED pin/polarity moved to the implementation's `config.h` (`ledPin`/`ledOnLevel`) — `CroasterConstants.h` no longer defines display/LED config
- `CroasterWiFiManager::restart()/erase()` replace the old `restartESP()/eraseESP()` helpers

---

## [0.51] — 2026-06-01

### Changed
- Refactored OTA handling to return a JSON progress string directly while simplifying internal state management
- Updated `BleManager` and `WebSocketManager` to use the streamlined OTA progress flow
- Simplified command and core OTA integration paths for the new handler contract

---

## [0.50] — 2026-05-30

### Added
- **OTA over BLE** (ESP32 only): firmware updates can now be performed via BLE in addition to WebSocket/WiFi
- Timeout checks during BLE OTA to handle stalled transfers

### Changed
- Improved OTA status reporting: `OtaHandler` now returns an `OtaResult` struct containing a JSON progress payload and an error flag
- Simplified `OtaHandler` internals — reduced code size while improving clarity
- `BleManager` updated to relay OTA binary data to `OtaHandler` and forward progress JSON back to the BLE client
- `WebSocketManager` updated to forward OTA progress JSON back to the WebSocket client consistently

---

## [0.46] — 2026-05-28

### Added
- `getExtra` command with corresponding data generation methods (`genRandomString`, random number/boolean)

### Changed
- Refactored command handling and improved JSON response generation
- Simplified command handling by removing `restart` and `erase` parameters from `handleJsonCommand`

### Fixed
- Removed `.DS_Store` files and added to `.gitignore`

---

## [0.45] — 2026-02-28 to 2026-05-13

### Added
- `displayToggle` command to toggle OLED display on/off
- BLE MTU set to 517 for improved throughput
- `genRandomString` function for generating random strings
- Indonesian FAQ (`FAQ_ID.md`) and Indonesian README (`README_ID.md`) translations
- Issue and pull request templates for contribution guidelines

### Changed
- Updated firmware progress display during OTA updates
- Updated library dependencies (`platformio.ini`)
- Set `dummyMode` to `false` (production default)

### Fixed
- Corrected spelling of `genRandomString`
- Updated JSON handling comments
- Updated WiFiManager library version and improved `platformio.ini` formatting

---

## [0.44] — 2025-05-15

### Added
- SSID name included in JSON data response

### Fixed
- Updated firmware version to `0.44`

---

## [0.42 – 0.43] — 2025-05-01 to 2025-05-06

### Added
- Custom partition configuration (`custom32c3sm.csv`) for ESP32C3 Super Mini to support OTA
- OTA update handling via `OtaHandler` class
- `resetState` method in `OtaHandler`; updated `begin` method to call it

### Changed
- Refactored `OtaHandler`: replaced `debugf` with `debugln`, updated `finalize` method
- Refactored `DisplayManager` to handle OLED presence checks and simplify `begin` method
- Streamlined WiFi setup by removing redundant mode setting
- Standardized temperature variable naming across `CroasterCore` and `DisplayManager`
- Updated temperature handling and command processing for improved clarity

### Fixed
- Initialized `Wire` in `isOledPresent` to ensure proper I2C communication
- Updated `dummyMode` to `false` and set WiFi mode in setup

---

## [0.41] — 2025-05-01

### Added
- OTA update handling; firmware version bumped to `0.41`

### Changed
- Removed OTA handling from `BleManager` (moved to dedicated `OtaHandler`)

---

## [0.40] — 2025-05-01

### Changed
- Refactored firmware to version `0.40`
- Added partitions configuration and reference link

---

## [0.31] — 2025-04-25 to 2025-04-28

### Changed
- Updated GPIO pin assignments in README
- Enhanced device identity functions for IP and SSID retrieval
- Improved JSON command handling in `CommandHandler`
- Enhanced sensor reading logic in `CroasterCore`
- Optimized display management in `DisplayManager`
- Updated blink logic and delay in `CommandHandler`
- Added `blinkIndicator` method in `DisplayManager`
- Adjusted `intervalSendData` handling for consistent timing

---

## [0.30 – Refactor Period] — 2025-04-22 to 2025-04-26

### Added
- `DeviceIdentity` class for chip ID, device name, IP address helpers
- Loop functions for `WebSocket` and `WiFiManager` for better code organization
- Screen rotation functionality in `DisplayManager`
- `testdrawline` function in `DisplayManager` for visual debugging
- IP address display toggle in `DisplayManager`
- `CommandHandler` class for centralized JSON command parsing and dispatching (BLE & WebSocket)
- ESP32 and ESP8266 conditional compilation (`#if defined(ESP32)` / `#if defined(ESP8266)`)
- Detailed class and method documentation (Doxygen-style headers)

### Changed
- Integrated `DisplayManager` into command handling and BLE setup
- Refactored BLE setup to use device name and `CommandHandler`
- Simplified BLE and WebSocket handling by integrating `CommandHandler`
- Updated `getDeviceName` and `getShortChipId` functions for improved prefix/suffix handling
- Optimized setup sequence — `Serial` initialization before manager setup
- Modularized command handling and improved temperature reading logic
- Updated JSON command handling to use proper JSON serialization and logging
- Changed `croasterInterval` type to `unsigned long` in `DisplayManager`
- Reordered constructor initialization in `WebSocketManager`
- Removed inheritance from `BLEServerCallbacks` and `BLECharacteristicCallbacks` in `BleManager`

### Fixed
- Changed `croasterInterval` type to `unsigned long` for consistency in `broadcastData`
- Updated git clone URL to use SSH format in README files

---

## [2.48] — 2025-02-24

### Changed
- Updated pin definitions
- Refactored display output and WiFi handling
- Renamed target directory and file for clarity
- Removed unused library

---

## [2.47] — 2025-02-24

### Changed
- Updated pin definitions and refactored code

---

## [2.46] — 2025-02-21

### Changed
- Minor bump; version consistency update

---

## [2.45] — 2025-02-21

### Changed
- Added Croaster Arduino sketch (`.ino`) and updated conversion script
- Updated `copy_to_ino.sh` to generate the Arduino sketch; implemented BLE server functionality
- Added conversion script for `main.cpp` and `Croaster.h`; refactored BLE characteristic handling

---

## [Early Refactor — ESP32 Core] — 2025-02-20 to 2025-02-24

### Added
- `Croaster` class with sensor integration, temperature conversion, and JSON data handling
- LED blinking functionality based on WiFi and BLE connection status
- BLE server functionality (`BleManager`)

### Changed
- Updated serial communication speeds and flash size in `platformio.ini`
- Refactored BLE data handling to use `String` type
- Updated Croaster class to use new MAX6675 library
- Adjusted pin definitions for new hardware
- Enhanced dummy data handling

---

## [Initial Modular Refactor] — 2025-04-19 to 2025-04-21

### Added
- File conversion script (`copy_to_ino.sh`) using Bash for Arduino sketch generation
- Dedicated `src/` directory structure for modular C++ source files

### Changed
- Replaced `TempsManager` with `CroasterCore` across the codebase
- Modularized codebase: `BleManager`, `WiFiManagerUtil`, `WebSocketManager`, `DisplayManager`, `CroasterCore`
- Updated `DisplayManager` methods for improved data handling and display updates
- Replaced Dart file copying logic with a Bash script

---

## [Pre-Modular] — 2021-02-07 to 2025-02-19

### Added
- Initial project commit with ESP32-based BLE coffee roaster monitor (2021-02-07)
- Arduino `.ino` file support
- PlatformIO configuration (`platformio.ini`) for ESP8266 and ESP32
- Basic Croaster class with sensor integration and JSON data output
- README and documentation (English)
- Artisan Roaster Scope connection instructions

### Changed
- Updated project from Arduino-only to PlatformIO build system
- Updated to production dummy data settings
- Progressively enhanced display output, WiFi handling, and BLE connectivity
- Updated README multiple times for wiring diagrams, hardware components, and connection guides

---

*For full commit history, run:*
```bash
git log --oneline
```

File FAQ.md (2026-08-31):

# ❓ Croaster FAQ — Frequently Asked Questions

> 🇮🇩 Versi Bahasa Indonesia tersedia di [FAQ_ID.md](FAQ_ID.md)

---

## 📦 General

### What is Croaster?

Croaster is an open-source firmware for ESP8266 and ESP32C3-based microcontrollers that turns your hardware into a coffee roasting temperature monitor. It reads two thermocouple sensors (Bean Temperature and Environment Temperature), calculates Rate of Rise (RoR), and streams data over WiFi (WebSocket) or BLE to compatible apps like Artisan Roaster Scope and ICRM.

---

### Which microcontrollers are supported?

| Board | WiFi | BLE | OTA (WiFi) | OTA (BLE) |
|:---|:---:|:---:|:---:|:---:|
| NodeMCU ESP8266 | ✅ | ❌ | ✅ | ❌ |
| ESP32C3 Super Mini | ✅ | ✅ | ✅ | ✅ |

---

### What apps can I use with Croaster?

- **[Artisan Roaster Scope](https://artisan-scope.org/)** — connects via WebSocket (WiFi). Available for Windows, macOS, and Linux.
- **[ICRM App](https://iiemb.github.io/#/icrm)** — connects via WebSocket (WiFi) or BLE (ESP32 only). Available for Android.

---

### Is Croaster free to use?

Yes. Croaster is released under the **MIT License**, which means it is free for both personal and commercial use. You can modify, distribute, and build upon it freely.

---

## 🔌 Hardware

### What sensors does Croaster use?

Croaster uses two **MAX6675** thermocouple ADC modules with **K-type thermocouple probes**:
- **BT (Bean Temperature)** — placed inside the roasting drum to measure bean temperature
- **ET (Environment Temperature)** — placed at the exhaust or inlet to measure airflow temperature

---

### Can I use only one sensor?

The firmware is designed to read two sensors. If you connect only one, the missing sensor will likely report `0` or erratic values. You can modify `CroasterCore.cpp` to handle a single-sensor setup, but this is not officially supported.

---

### What is the operating voltage for the components?

All components (OLED display, MAX6675 modules, and the microcontroller) operate at **3.3V**. Do not connect any of these to 5V directly, as it may damage the components.

---

### Do both sensors share the same SPI pins?

Yes. Both MAX6675 sensors share the **SCK** and **SO** SPI lines. They are differentiated by individual **CS (Chip Select)** pins:
- **BT sensor CS:** `D8` (ESP8266) / `GPIO7` (ESP32C3)
- **ET sensor CS:** `D6` (ESP8266) / `GPIO6` (ESP32C3)

---

## 📶 WiFi & Connectivity

### How do I connect Croaster to my WiFi network?

On first boot, Croaster creates its own WiFi access point named `[XXXX] Croaster-XXXX`. Connect to it from your phone or computer, and a captive portal page will open. Enter your home WiFi credentials there — Croaster will save them and connect automatically on future boots.

See the [WiFi Setup Video](https://www.youtube.com/watch?v=esNiudoCEcU&t=434s) for a visual guide.

---

### I forgot my WiFi password or want to change the network. How do I reset?

Send the command `{"command": "erase"}` via WebSocket or BLE (ICRM app), or press the reset button while holding the boot button on the ESP32C3. This erases saved WiFi credentials and puts Croaster back into access point mode for reconfiguration.

---

### Can I use Croaster without a WiFi network?

Yes. When Croaster is not connected to any WiFi network, it broadcasts its own access point. You can connect Artisan directly to that access point. See [Option 1 in the README](README.md#-option-1-direct-connection-croaster-as-access-point).

---

### What is the WebSocket port?

Croaster's WebSocket server runs on **port 81**.

---

### How often does Croaster send data?

By default, data is broadcast every **3 seconds**. You can change this by sending:
```json
{"command": {"interval": 5}}
```
Replace `5` with your desired interval in seconds.

---

### Is BLE available on ESP8266?

No. BLE is only available on the **ESP32** platform. The ESP8266 only supports WiFi.

---

## 🌡️ Temperature & Sensors

### What temperature units are supported?

Croaster supports **Celsius (C)** and **Fahrenheit (F)**. Switch units by sending:
```json
{"command": {"tempUnit": "F"}}
```
or
```json
{"command": {"tempUnit": "C"}}
```

---

### What is Rate of Rise (RoR)?

Rate of Rise (RoR) measures how fast the temperature is increasing, expressed in **degrees per minute**. Croaster calculates RoR for both BT and ET automatically based on recent sensor history. RoR is a critical metric in coffee roasting for tracking the development phase.

---

### My sensor readings seem noisy or unstable. What can I do?

Croaster applies a **smoothing filter** (factor: 5) to reduce noise from the MAX6675 sensors. If readings are still unstable, check your wiring, ensure the thermocouple probes are securely seated in the MAX6675 modules, and make sure the VCC supply is stable at 3.3V.

---

### Can I apply a temperature correction/offset?

Yes. Send a correction command:
```json
{"command": {"correctionBt": 1.5, "correctionEt": -0.5}}
```
This applies a `+1.5°` offset to BT and a `-0.5°` offset to ET. The correction is applied on top of the smoothed sensor reading.

---

## 🔧 Build & Upload

### Which build method should I use?

**PlatformIO is the only supported workflow** (Arduino IDE is not used). Each
board has its own folder:

| Board | Folder | Command |
|:---|:---|:---|
| ESP8266 (NodeMCU / ESP-12E) | `boards/esp8266/` | `pio run -e esp8266 -t upload` |
| ESP32-C3 Super Mini | `boards/esp32c3/` | `pio run -e esp32c3 -t upload` |

---

### What is the `custom32c3sm.csv` file?

It is a **custom partition table** for the ESP32C3 Super Mini. This partition layout allocates more storage for the application (`1900544` bytes) while still reserving space for OTA updates. Without it, OTA updates cannot coexist with a large firmware binary. It lives in `boards/esp32c3/` and is referenced by `boards/esp32c3/platformio.ini` (`board_build.partitions = custom32c3sm.csv`).

---

## ⬆️ OTA Updates

### How do I update the firmware over the air?

Use the **ICRM app** on Android. The app supports OTA over both WiFi (WebSocket) and BLE (ESP32 only):

- **WiFi OTA:** The app sends the compiled firmware binary over WebSocket. Croaster receives it in chunks, writes it to flash, and restarts automatically once complete.
- **BLE OTA:** The app sends the firmware binary over BLE. `CroasterBleManager` relays the data to `CroasterOtaHandler`, which processes it in chunks with timeout checks. Progress is reported back to the app as JSON.

---

### OTA doesn't work on my ESP32C3. Why?

The most common reason is that the partition scheme does not reserve space for OTA. The ESP32-C3 implementation uses the custom `custom32c3sm.csv` partition (set in `platformio.ini`), which reserves an OTA slot. Re-flash with that partition and OTA will work.

---

### Does OTA work on ESP8266?

OTA via WiFi (WebSocket) using the ICRM app is supported on ESP8266, as long as you are using a partition scheme that includes OTA space (the default NodeMCU scheme supports this). BLE OTA is not available on ESP8266.

---

## 🧪 Development

### How do I test Croaster without physical sensors?

Set `dummyMode = true` in `boards/esp32c3/src/config.h`:
```cpp
const bool dummyMode = true;
```
In this mode, Croaster generates simulated temperature data, so you can test the WebSocket connection, OLED display, and BLE without attaching any hardware.

---

### How do I add a custom command?

Custom commands are registered in your implementation's `main.cpp` — **no
library edits needed**. Callbacks return a response string (empty = no response):

For a **basic string command**, use `onCommand`:
```cpp
app.commands().onCommand("mycommand", [](const JsonObject &json) -> String {
    return "{\"status\": \"ok\"}";
});
```
Send it as: `{"command": "mycommand"}`

For a **configuration command** (key-value style), use `onJsonCommand`:
```cpp
app.commands().onJsonCommand("mykey", [](const JsonObject &json) -> String {
    String myValue = json["mykey"].as<String>();
    // your logic here
    return "";
});
```
Send it as: `{"command": {"mykey": "somevalue"}}`

Both types are available over WebSocket and BLE automatically.

---

### What JSON format does Croaster broadcast?

Croaster sends a JSON payload over WebSocket and BLE at each interval. The payload includes temperature readings, RoR values, a timer, and the firmware version. The exact structure can be found in `CroasterCore.cpp` and `CroasterWebSocketManager.cpp`.

---

## 🐛 Troubleshooting

### Croaster is not showing on my WiFi list.

- Wait up to 30 seconds after powering on for the access point to appear.
- If Croaster was previously connected to a WiFi network, it will try to reconnect first. Hold the boot button during startup to force AP mode (or erase credentials).
- Check that your power supply provides sufficient current for the ESP32C3.

---

### The OLED display is blank or shows garbage.

- Verify that the SDA/SCL wires are not swapped.
- Confirm the I2C address. The SSD1306 usually uses `0x3C`. If yours uses `0x3D`, update `CroasterDisplaySSD1306.cpp` in `boards/esp32c3/src/`.
- Check the 3.3V supply to the display.

---

### Artisan shows "no connection" even though I'm on the same network.

- Confirm the IP address shown on the Croaster OLED matches what you entered in Artisan.
- Make sure both devices are on the same network (same router, not guest vs. main network).
- Check that port `81` is not blocked by your firewall or router settings.
- Try restarting Croaster and reconnecting.

---

### The temperature readings are stuck at 0 or show `-0`.

- Check the wiring of the MAX6675 sensor, especially the CS pin.
- Make sure the K-type thermocouple is firmly plugged into the MAX6675 module.
- Verify your 3.3V power supply is stable.
- Try swapping the sensor modules to rule out a faulty unit.

---

_Have a question that isn't answered here? Open an issue on [GitHub](https://github.com/IiemB/Croaster)._

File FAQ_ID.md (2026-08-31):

# ❓ Croaster FAQ — Pertanyaan yang Sering Diajukan

> 🇬🇧 English version available at [FAQ.md](FAQ.md)

---

## 📦 Umum

### Apa itu Croaster?

Croaster adalah firmware open-source untuk mikrokontroler berbasis ESP8266 dan ESP32C3 yang mengubah hardware Anda menjadi monitor suhu sangrai kopi. Firmware ini membaca dua sensor termokopel (Suhu Biji dan Suhu Lingkungan), menghitung Rate of Rise (RoR), dan mengirimkan data melalui WiFi (WebSocket) atau BLE ke aplikasi yang kompatibel seperti Artisan Roaster Scope dan ICRM.

---

### Mikrokontroler apa saja yang didukung?

| Board | WiFi | BLE | OTA (WiFi) | OTA (BLE) |
|:---|:---:|:---:|:---:|:---:|
| NodeMCU ESP8266 | ✅ | ❌ | ✅ | ❌ |
| ESP32C3 Super Mini | ✅ | ✅ | ✅ | ✅ |

---

### Aplikasi apa yang bisa digunakan bersama Croaster?

- **[Artisan Roaster Scope](https://artisan-scope.org/)** — terhubung via WebSocket (WiFi). Tersedia untuk Windows, macOS, dan Linux.
- **[Aplikasi ICRM](https://iiemb.github.io/#/icrm)** — terhubung via WebSocket (WiFi) atau BLE (khusus ESP32). Tersedia untuk Android.

---

### Apakah Croaster gratis digunakan?

Ya. Croaster dirilis di bawah **Lisensi MIT**, yang berarti gratis untuk penggunaan pribadi maupun komersial. Anda bebas memodifikasi, mendistribusikan, dan mengembangkannya.

---

## 🔌 Hardware

### Sensor apa yang digunakan Croaster?

Croaster menggunakan dua modul ADC termokopel **MAX6675** dengan **probe termokopel K-type**:
- **BT (Bean Temperature / Suhu Biji)** — ditempatkan di dalam drum sangrai untuk mengukur suhu biji kopi
- **ET (Environment Temperature / Suhu Lingkungan)** — ditempatkan di exhaust atau inlet untuk mengukur suhu aliran udara

---

### Bisakah saya menggunakan hanya satu sensor?

Firmware dirancang untuk membaca dua sensor. Jika hanya satu sensor yang terpasang, sensor yang tidak terpasang kemungkinan akan melaporkan `0` atau nilai yang tidak stabil. Anda dapat memodifikasi `CroasterCore.cpp` untuk setup satu sensor, namun ini tidak didukung secara resmi.

---

### Berapa tegangan operasi komponen-komponen tersebut?

Semua komponen (layar OLED, modul MAX6675, dan mikrokontroler) beroperasi pada **3.3V**. Jangan hubungkan komponen ini langsung ke 5V, karena dapat merusak komponen.

---

### Apakah kedua sensor menggunakan pin SPI yang sama?

Ya. Kedua sensor MAX6675 berbagi jalur **SCK** dan **SO** pada bus SPI. Keduanya dibedakan oleh pin **CS (Chip Select)** masing-masing:
- **CS sensor BT:** `D8` (ESP8266) / `GPIO7` (ESP32C3)
- **CS sensor ET:** `D6` (ESP8266) / `GPIO6` (ESP32C3)

---

## 📶 WiFi & Konektivitas

### Bagaimana cara menghubungkan Croaster ke jaringan WiFi saya?

Pada boot pertama, Croaster membuat access point WiFi sendiri dengan nama `[XXXX] Croaster-XXXX`. Hubungkan dari ponsel atau komputer Anda, dan halaman captive portal akan terbuka secara otomatis. Masukkan kredensial WiFi rumah Anda di sana — Croaster akan menyimpannya dan terhubung otomatis di boot berikutnya.

Lihat [Video Setup WiFi](https://www.youtube.com/watch?v=esNiudoCEcU&t=434s) untuk panduan visual.

---

### Saya lupa password WiFi atau ingin mengganti jaringan. Bagaimana cara mereset?

Kirim perintah `{"command": "erase"}` via WebSocket atau BLE (aplikasi ICRM), atau tekan tombol reset sambil menahan tombol boot pada ESP32C3. Ini akan menghapus kredensial WiFi yang tersimpan dan menempatkan Croaster kembali ke mode access point untuk konfigurasi ulang.

---

### Bisakah saya menggunakan Croaster tanpa jaringan WiFi?

Ya. Ketika Croaster tidak terhubung ke jaringan WiFi manapun, ia menyiarkan access point-nya sendiri. Anda dapat menghubungkan Artisan langsung ke access point tersebut. Lihat [Opsi 1 di README](README_ID.md#-opsi-1-koneksi-langsung-croaster-sebagai-access-point).

---

### Berapa port WebSocket yang digunakan?

Server WebSocket Croaster berjalan di **port 81**.

---

### Seberapa sering Croaster mengirim data?

Secara default, data di-broadcast setiap **3 detik**. Anda dapat mengubahnya dengan mengirim:
```json
{"command": {"interval": 5}}
```
Ganti `5` dengan interval yang Anda inginkan dalam satuan detik.

---

### Apakah BLE tersedia di ESP8266?

Tidak. BLE hanya tersedia di platform **ESP32**. ESP8266 hanya mendukung WiFi.

---

## 🌡️ Suhu & Sensor

### Satuan suhu apa saja yang didukung?

Croaster mendukung **Celsius (C)** dan **Fahrenheit (F)**. Ganti satuan dengan mengirim:
```json
{"command": {"tempUnit": "F"}}
```
atau
```json
{"command": {"tempUnit": "C"}}
```

---

### Apa itu Rate of Rise (RoR)?

Rate of Rise (RoR) mengukur seberapa cepat suhu meningkat, dinyatakan dalam **derajat per menit**. Croaster menghitung RoR untuk BT dan ET secara otomatis berdasarkan riwayat sensor terbaru. RoR adalah metrik kritis dalam sangrai kopi untuk memantau fase perkembangan.

---

### Pembacaan sensor saya terlihat tidak stabil. Apa yang harus saya lakukan?

Croaster menerapkan **filter penghalusan** (faktor: 5) untuk mengurangi noise dari sensor MAX6675. Jika pembacaan masih tidak stabil, periksa kabel Anda, pastikan probe termokopel terpasang dengan kuat di modul MAX6675, dan pastikan suplai VCC stabil di 3.3V.

---

### Bisakah saya menerapkan koreksi/offset suhu?

Ya. Kirim perintah koreksi:
```json
{"command": {"correctionBt": 1.5, "correctionEt": -0.5}}
```
Ini menerapkan offset `+1.5°` pada BT dan offset `-0.5°` pada ET. Koreksi diterapkan di atas pembacaan sensor yang sudah dihaluskan.

---

## 🔧 Build & Upload

### Metode build mana yang sebaiknya saya gunakan?

**PlatformIO adalah satu-satunya alur kerja yang didukung** (Arduino IDE tidak digunakan). Setiap board memiliki folder sendiri:

| Board | Folder | Perintah |
|:---|:---|:---|
| ESP8266 (NodeMCU / ESP-12E) | `boards/esp8266/` | `pio run -e esp8266 -t upload` |
| ESP32-C3 Super Mini | `boards/esp32c3/` | `pio run -e esp32c3 -t upload` |

---

### Apa itu file `custom32c3sm.csv`?

Ini adalah **tabel partisi kustom** untuk ESP32C3 Super Mini. Tata letak partisi ini mengalokasikan lebih banyak penyimpanan untuk aplikasi (`1900544` byte) sekaligus menyisihkan ruang untuk update OTA. Tanpanya, update OTA tidak dapat berjalan berdampingan dengan binary firmware yang besar. File ini berada di `boards/esp32c3/` dan dirujuk oleh `boards/esp32c3/platformio.ini` (`board_build.partitions = custom32c3sm.csv`).

---

## ⬆️ Update OTA

### Bagaimana cara memperbarui firmware secara over the air?

Gunakan **aplikasi ICRM** di Android. Aplikasi mendukung OTA melalui WiFi (WebSocket) maupun BLE (khusus ESP32):

- **OTA via WiFi:** Aplikasi mengirimkan binary firmware yang telah dikompilasi melalui WebSocket. Croaster menerimanya dalam potongan-potongan, menuliskannya ke flash, dan restart otomatis setelah selesai.
- **OTA via BLE:** Aplikasi mengirimkan binary firmware melalui BLE. `CroasterBleManager` meneruskan data ke `CroasterOtaHandler`, yang memprosesnya secara bertahap dengan pemeriksaan timeout. Progres dilaporkan kembali ke aplikasi sebagai JSON.

---

### OTA tidak bekerja di ESP32C3 saya. Mengapa?

Alasan paling umum adalah skema partisi tidak menyisihkan ruang untuk OTA. Implementasi ESP32-C3 menggunakan partisi kustom `custom32c3sm.csv` (diatur di `platformio.ini`), yang menyisihkan slot OTA. Flash ulang dengan partisi tersebut dan OTA akan berfungsi.

---

### Apakah OTA bekerja di ESP8266?

OTA via WiFi (WebSocket) menggunakan aplikasi ICRM didukung di ESP8266, selama Anda menggunakan skema partisi yang mencakup ruang OTA (skema NodeMCU default mendukung ini). OTA via BLE tidak tersedia di ESP8266.

---

## 🧪 Pengembangan

### Bagaimana cara menguji Croaster tanpa sensor fisik?

Atur `dummyMode = true` di `boards/esp32c3/src/config.h`:
```cpp
const bool dummyMode = true;
```
Dalam mode ini, Croaster menghasilkan data suhu simulasi, sehingga Anda dapat menguji koneksi WebSocket, tampilan OLED, dan BLE tanpa memasang hardware apapun.

---

### Bagaimana cara menambahkan perintah kustom?

Perintah kustom didaftarkan di `main.cpp` implementasi Anda — **tanpa perlu
mengubah library**. Callback mengembalikan string respons (kosong = tanpa respons):

Untuk **perintah dasar (string)**, gunakan `onCommand`:
```cpp
app.commands().onCommand("perintahsaya", [](const JsonObject &json) -> String {
    return "{\"status\": \"ok\"}";
});
```
Kirim sebagai: `{"command": "perintahsaya"}`

Untuk **perintah konfigurasi** (format key-value), gunakan `onJsonCommand`:
```cpp
app.commands().onJsonCommand("kuncisaya", [](const JsonObject &json) -> String {
    String nilai = json["kuncisaya"].as<String>();
    // logika Anda di sini
    return "";
});
```
Kirim sebagai: `{"command": {"kuncisaya": "nilaitertentu"}}`

Kedua tipe tersedia melalui WebSocket maupun BLE secara otomatis.

---

### Format JSON apa yang di-broadcast oleh Croaster?

Croaster mengirimkan payload JSON melalui WebSocket dan BLE di setiap interval. Payload tersebut mencakup pembacaan suhu, nilai RoR, timer, dan versi firmware. Struktur lengkapnya dapat ditemukan di `CroasterCore.cpp` dan `CroasterWebSocketManager.cpp`.

---

## 🐛 Pemecahan Masalah

### Croaster tidak muncul di daftar WiFi saya.

- Tunggu hingga 30 detik setelah dinyalakan agar access point muncul.
- Jika Croaster sebelumnya terhubung ke jaringan WiFi, ia akan mencoba terhubung kembali terlebih dahulu. Tahan tombol boot saat startup untuk memaksa mode AP (atau hapus kredensial).
- Periksa apakah catu daya Anda menyediakan arus yang cukup untuk ESP32C3.

---

### Layar OLED kosong atau menampilkan karakter tidak jelas.

- Verifikasi bahwa kabel SDA/SCL tidak tertukar.
- Konfirmasi alamat I2C. SSD1306 biasanya menggunakan `0x3C`. Jika milik Anda menggunakan `0x3D`, perbarui `CroasterDisplaySSD1306.cpp` di `boards/esp32c3/src/`.
- Periksa suplai 3.3V ke layar.

---

### Artisan menampilkan "no connection" meskipun saya berada di jaringan yang sama.

- Konfirmasi alamat IP yang ditampilkan di OLED Croaster sesuai dengan yang Anda masukkan di Artisan.
- Pastikan kedua perangkat berada di jaringan yang sama (router yang sama, bukan jaringan guest vs. utama).
- Periksa apakah port `81` tidak diblokir oleh firewall atau pengaturan router Anda.
- Coba restart Croaster dan hubungkan kembali.

---

### Pembacaan suhu macet di 0 atau menampilkan `-0`.

- Periksa kabel sensor MAX6675, terutama pin CS.
- Pastikan probe termokopel K-type terpasang kuat di modul MAX6675.
- Verifikasi suplai daya 3.3V Anda stabil.
- Coba tukar modul sensor untuk mengetahui apakah ada unit yang rusak.

---

_Ada pertanyaan yang belum terjawab di sini? Buka issue di [GitHub](https://github.com/IiemB/Croaster)._

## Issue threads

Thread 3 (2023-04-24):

Control option?

Alisdairharden, 2023-04-24:
Hi liem,
I have just ordered the parts to make my own croaster! This is exactly what I have been looking for. It's great to have the option of using either a phone or artisan.

I was wondering if you had any plans to integrate ssr control either through artisan or the croaster app? Or would WiFi be too slow for heat control

touchcure, 2025-05-31:
Hallo Liem, saya beneran ga ngerti cara menggunakan platformio dll. Tapi saya udah beli hardware-nya. Bisa bantu ga cara²nya?

Closed 2025-05-31.

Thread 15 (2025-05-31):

How to use Platformio

IiemB, 2025-05-31:
> Hallo Liem, saya beneran ga ngerti cara menggunakan platformio dll. Tapi saya udah beli hardware-nya. Bisa bantu ga cara²nya?

 _Originally posted by @touchcure in [#3](https://github.com/IiemB/Croaster/issues/3#issuecomment-2925128750)_

IiemB, 2025-05-31:
If you're not familiar with using PlatformIO yet, I recommend starting with the Arduino IDE. However, if you're using an ESP32C3 chip, it requires a bit of setup—as I’ve explained [**here**](https://github.com/IiemB/Croaster?tab=readme-ov-file#-arduino-ide-required-for-esp32c3).

If you're just following my default setup (without any custom hardware or commands), you can download the prebuilt .bin files from the [**Releases page**](https://github.com/IiemB/Croaster/releases) and flash them to your chip using [**ESP-Flasher**](https://github.com/Jason2866/ESP_Flasher).

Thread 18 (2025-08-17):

PID controll

StrobesAV, 2025-08-17:
Hi, I was looking for this software with support for current hardware for a while. Thank you!
Any plans to support PID feature offered by Artisan?
I'd love to test any code you may have and report back.
There are some examples on Github. Unfortunately I was not able to make them work. For example, also using Web Socket protocol: https://github.com/LeFish1/ESP8266_CoffeeRoaster (libraries are outdated. May needs a older ESP framework to compile without errors. It was not maintained for while.)
Also I can help with MQTT integration in to Home Assistant (https://www.home-assistant.io/)

StrobesAV, 2025-08-17:
I was trying to compile the code for esp8266, and got this error. May be need some help.
( I checked and re-installed libraries. the io.h is present in the` library\avr`)
Still reading about this. Is the ESP non AVR device?
Thank you!

```
In file included from C:\Users\pilot\.platformio\packages\framework-arduinoespressif8266\cores\esp8266/Arduino.h:292,
                 from src\CommandHandler.h:2,
                 from src\CommandHandler.cpp:1:
C:\Users\pilot\Documents\Arduino\libraries\avr/pgmspace.h:90:10: fatal error: avr/io.h: No such file or directory
   90 | #include <avr/io.h>
      |          ^~~~~~~~~~
compilation terminated.

```

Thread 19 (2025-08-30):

BLE support for ESP8266

StrobesAV, 2025-08-30:
Hi, I'm having problems with WS, unstable connection with Artisan. And would like to test it with BLE. Can you give some ideas how to enable BLE for ESP8266. Thank you.

IiemB, 2025-09-01:
BLE is not available on ESP8266 (the chip doesn’t have BLE hardware). If you want to test BLE, you’ll need to switch to an ESP32-based board (e.g., ESP32-C3 SuperMini). BLE support in Croaster is intended for pairing with the [ICRM app](https://play.google.com/store/apps/details?id=com.iiemb.croaster). Artisan itself does not speak BLE, so for Artisan you should continue using WebSocket (Wi-Fi)

Closed 2025-09-01.

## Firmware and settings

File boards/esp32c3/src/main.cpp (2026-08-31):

#include <Arduino.h>
#include <ArduinoJson.h>

// Implementation configuration (pins, dummy mode, LED) — edit config.h.
#include "config.h"

// Shared SSD1306 display (boards/common) used by this board.
#include <CroasterDisplaySSD1306.h>

// Single entry-point application wrapper (begin()/loop() only).
#include <CroasterApp.h>

// Board id reported to the app (getDeviceInfo "board") — hardcoded here.
#include <CroasterDeviceIdentity.h>

// Board wiring: the core and the display are created here so CroasterApp never
// needs to know the display specification.
CroasterCore core(dummyMode, pins);
CroasterDisplaySSD1306 display(core);
CroasterApp app(core, &display, ledPin, ledOnLevel);

// ---------------------------------------------------------------------------
// Optional: register custom commands WITHOUT touching the Croaster library.
//
//   onCommand("name", fn)      -> basic string command:  {"command":"name"}
//   onJsonCommand("key", fn)   -> nested JSON command:   {"command":{"key":...}}
//
// Each callback receives the parsed JSON object and returns a response string
// (empty = no response is sent back). genResponseCommand() can wrap a response
// in the standard {"command","response"} format.
// ---------------------------------------------------------------------------
void registerCustomCommands() {}

void setup() {
    // Hardcode this board's id (matches the app's CroasterBoardTypes enum).
    CroasterDeviceIdentity::setBoardName("ESP32-C3");

    registerCustomCommands();
    app.begin();
}

void loop() {
    app.loop();
}

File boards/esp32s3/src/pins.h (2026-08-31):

#pragma once

// ============================================================================
// ES3C28P (ESP32-S3 2.8" ILI9341 LCD) display pin layout — edit this file.
// Used by the LVGL UI (LvglUi.cpp) and the FT6336G touch driver (LvglTouch.cpp).
// The thermocouple pins and LED live in config.h.
// ============================================================================

// Adafruit ILI9341 (SPI) — backlight via LEDC PWM on IO45.
#define LCD_CS_PIN 10
#define LCD_DC_PIN 46
#define LCD_SCLK_PIN 12
#define LCD_MOSI_PIN 11
#define LCD_MISO_PIN 13
#define LCD_RST_PIN (-1) // tied to the board's reset
#define LCD_BL_PIN 45

// FT6336G capacitive touch (I2C, address 0x38).
#define TOUCH_SDA_PIN 16
#define TOUCH_SCL_PIN 15
#define TOUCH_RST_PIN 18
#define TOUCH_INT_PIN 17

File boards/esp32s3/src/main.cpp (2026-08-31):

#include <Arduino.h>
#include <ArduinoJson.h>

// Implementation configuration (pins, dummy mode, LED) — edit config.h.
#include "config.h"

// ES3C28P LVGL display on the built-in ILI9341 LCD (impl src/CroasterDisplayS3.h).
#include <CroasterDisplayS3.h>

// Single entry-point application wrapper (begin()/loop() only).
#include <CroasterApp.h>

// Board id reported to the app (getDeviceInfo "board") — hardcoded here.
#include <CroasterDeviceIdentity.h>

// Board wiring: the core and the display are created here so CroasterApp never
// needs to know the display specification.
CroasterCore core(dummyMode, pins);
CroasterDisplayS3 display(core);
CroasterApp app(core, &display, ledPin, ledOnLevel);

// ---------------------------------------------------------------------------
// Optional: register custom commands WITHOUT touching the Croaster library.
//
//   onCommand("name", fn)      -> basic string command:  {"command":"name"}
//   onJsonCommand("key", fn)   -> nested JSON command:   {"command":{"key":...}}
//
// Each callback receives the parsed JSON object and returns a response string
// (empty = no response is sent back). genResponseCommand() can wrap a response
// in the standard {"command","response"} format.
//
// Here we expose the S3-only display controls (backlight brightness and the
// light/dark theme) so a client can drive them over WebSocket / BLE.
// ---------------------------------------------------------------------------
void registerCustomCommands() {
    // {"command":{"brightness":25}} -> set backlight (0-100), echo the new value
    app.commands().onJsonCommand("brightness", [](const JsonObject& json) -> String {
        if (!json["brightness"].is<int>())
            return ""; // ignore if not an integer

        int value = json["brightness"].as<int>();
        if (value < 0)
            value = 0;
        if (value > 100)
            value = 100;
        display.setBrightness(value);
        return "";
    });

    // {"command":{"darkMode":true}} -> switch light/dark theme, echo the new state
    app.commands().onJsonCommand("darkMode", [](const JsonObject& json) -> String {
        if (!json["darkMode"].is<bool>())
            return ""; // ignore if not a boolean

        bool value = json["darkMode"].as<bool>();
        display.setDarkMode(value);
        return "";
    });
}

void setup() {
    // Hardcode this board's id (matches the app's CroasterBoardTypes enum).
    CroasterDeviceIdentity::setBoardName("ESP32-S3");

    registerCustomCommands();
    app.begin();

    // Boot splash is driven by the LVGL task; let it switch to the main page
    // once the (minimum timed) splash has finished.
    display.finishSplash();
}

void loop() {
    // Keep the LVGL status chip in sync with the BLE client connection.
    display.setBtConnected(app.ble().isClientConnected());

    app.loop();
}

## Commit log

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2025-02-17 update README and configuration for Croaster project; change board to esp32 and remove unused README files
2025-02-17 remove README files and add Croaster class with sensor integration and JSON data handling
2025-02-19 add Croaster class with sensor integration, temperature conversion, and JSON data handling
2025-02-20 refactor BLE data handling to use String type and add Croaster class with sensor management and JSON data support
2025-02-24 update pin definitions and increment Croaster version to 2.47; refactor display output and WiFi handling
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2025-02-24 refactor: improve LED blinking logic based on WiFi and BLE connection status
2025-02-25 refactor: update Croaster class to use new MAX6675 library, adjust pin definitions, and enhance dummy data handling
2025-04-19 refactor: update Croaster instantiation to disable debug mode and adjust deltaTimer checks to prevent division by zero
    [main.cpp]
2025-04-19 feat: add testdrawline function to DisplayManager for visual debugging and adjust temperature text positioning
2025-04-19 Refactor and modularize codebase for BLE and WiFi management
    - Introduced `BleManager.h` and `BleManager.cpp` for BLE setup and handling.
    - Created `Constants.h` for shared constants and configuration values.
    - Removed `Croaster.h` and integrated its functionality into `TempsManager`.
    - Added `DisplayManager` class for OLED display management.
    - Implemented `PinConfig.h` for thermocouple pin assignments.
    - Developed `WebSocketManager` for handling WebSocket connections and events.
    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
2025-04-20 refactor: replace TempsManager with CroasterCore across the codebase
    [main.cpp]
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2025-04-23 refactor: update BLE setup to use device name and command handler, improve callback handling
2025-04-23 refactor: enhance README files with detailed features, hardware components, wiring diagrams, and software highlights
2025-04-25 refactor: update GPIO pin assignments in README and README_ID, improve JSON command handling in CommandHandler, enhance sensor reading logic in CroasterCore, and optimize display management in Displa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
2025-04-28 refactor: update firmware version to 0.31 and enhance device identity functions for IP and SSID retrieval
2025-04-30 feat: add partitions configuration, update firmware version to 0.41, and include reference link
    [partitions.csv]
2025-05-01 fix: update dummyMode to false and set WiFi mode in setup
    [main.cpp]
2025-05-01 feat: add custom partition configuration and update references for esp32c3 super mini
    [custom32c3sm.csv, partitions.csv]
2025-05-02 fix: initialize Wire in isOledPresent to ensure proper I2C communication
2025-05-06 refactor: update temperature handling and command processing for improved clarity and functionality
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2025-05-11 docs: update README to remove Indonesian version and enhance wiring diagram clarity
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2026-08-10 chore: update .gitignore to include new file patterns and add Enclosure.FCStd
    [Enclosure.FCStd]
2026-08-14 Add DisplayAnimation class and integrate fire animation into splash screen
    - Created a new DisplayAnimation class to handle fire animation display.
    - Integrated the fire animation into the DisplayManager's splash method, replacing the previous circle drawing logic.
    - Removed unnecessary delays and circle drawing code to streamline the splash screen animation.
    [Enclosure_V2.FCStd]
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2026-08-29 feat: decouple firmware into reusable display/pin-agnostic library
    - Repo root is now a PlatformIO/Arduino library (library.json + library.properties);
    reference firmware moved to examples/reference/ (esp32c3 + esp8266 envs) which
    consumes the library via ../.. exactly like an external project.
    - New CroasterDisplay abstract interface: the core is display-agnostic; consuming
    projects implement their own display (SSD1306 lives in the reference example as
    CroasterDisplaySSD1306). nullptr display is supported (headless boards).
    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
2026-08-29 feat: single begin()/loop() implementation API + custom command registration
    - Rename examples/ -> implementation/ (reference firmware is now
    implementation/reference/).
    - Add CroasterApp (implementation/reference/src/CroasterApp.h/.cpp): single
    begin()/loop() entry point wiring core, display, command handler, WebSocket,
    BLE and WiFi; main.cpp reduced to app.begin()/app.loop().
    - Add implementation config.h: pin layout + dummyMode live on the
    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
2026-08-29 feat: per-board implementation (esp32c3); display-agnostic CroasterApp; move display/LED config to implementation
    - Rename implementation/reference -> implementation/esp32c3 (per-board impls;
    esp8266 env dropped from the example — the library still supports it).
    - CroasterApp is now display-agnostic: takes CroasterCore& + CroasterDisplay*
    + LED pin/level; the concrete display type is defined in the implementation
    (main.cpp), so the app never knows the display specification.
    - Move display constants (SCREEN_WIDTH/SCREEN_HEIGHT/OLED_RESET) into
    CroasterDisplaySSD1306.h and LED pin/polarity into the implementation's
    config.h (ledPin/ledOnLevel); CroasterConstants.h no longer defines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
    [CroasterCommandHandler.cpp, CroasterDisplaySSD1306.cpp]
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2026-08-29 feat: ESP32-S3 (ES3C28P) implementation; roast timer; per-board boardName; build_all.sh
    - implementation/esp32s3/: LVGL 9 UI (src/ui/) + FT6336G touch on the
    ILI9341 LCD, ported from the ES3C28P branch into the per-board structure
    (CroasterDisplayS3 wrapping LvglUi); no CROASTER_ES3C28P compile-time guards
    - library: roast timer (roastTimerStart/Pause/Reset), getDeviceInfo reports
    board/darkMode/brightness, CroasterDisplay::isDarkMode()/getBrightness(),
    CroasterApp::ble(); CroasterDeviceIdentity::boardName() reads the
    per-implementation -DCROASTER_BOARD_NAME build flag
    - build_all.sh builds every board into the gitignored builds/ folder;
    AGENTS.md + CONTEXT.md added; esp32c3 part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
    [custom32c3sm.csv]
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2026-08-29 feat: restructure into croaster/ library + boards/; debug upload + release/debug split
    - Move the library (library.json, src/, test/) into croaster/ and all boards
    into boards/ (was implementation/); boards now consume the lib via
    lib_deps = ../../croaster
    - Add upload.sh (interactive debug build + upload of a connected board) and
    pin each board env to build_type = release with a <board>-debug variant
    - build_all.sh builds only the release env; docs updated for the new layout
    [custom32c3sm.csv]
2026-08-29 fix: correct sed version extraction + symlink:// lib_deps mapping
    - build_all.sh: fix broken sed regex in the version read (missing / before \1)
    - boards/*/platformio.ini: correct the symlink:// name->path mapping
    (Croaster -> ../../croaster, CroasterDisplaySSD1306 -> ../common)
    - docs: libs are now live-linked via symlink://, no .pio/libdeps clearing
2026-08-29 fix: replace deprecated containsKey in custom JSON dispatch; harden upload.sh debug deps
    - CroasterCommandHandler: use json[key].is<JsonVariant>() instead of the
    deprecated containsKey() (ArduinoJson 7)
    - upload.sh: drop the <board>-debug libdeps before building so a stale
    integrity.dat can never trigger PlatformIO's 'Removing unused dependencies'
    hang
    [CroasterCommandHandler.cpp]
2026-08-30 fix: defer BLE command parsing off the BTC task; rename upload.sh to upload_monitor.sh
    - CroasterBleManager: BLE callbacks run on the Bluedroid BTC task (~3KB stack);
    parsing commands with ArduinoJson there overflows it and crashes as an
    unrelated xQueueGenericSend assert (debug/single-core only). onWrite now
    only stores the payload + flag (OTA stays immediate); loop() runs the
    command handler on the Arduino loop task.
    - Rename upload.sh -> upload_monitor.sh (builds + uploads the debug firmware
    and opens the serial monitor); docs updated.
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2026-08-30 build: use registry links2004/WebSockets@^2.7.3 instead of git URL; fix esp32c3 upload
    - All boards + croaster/library.json: WebSockets dep via PlatformIO registry
    (links2004/WebSockets@^2.7.3) instead of the git URL — same lib v2.7.3
    - esp32c3: lower upload_speed to 460800 (board default) and enable the 1200bps
    USB touch reset to fix intermittent 'No serial data received' on flash
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2026-08-30 fix: silence -Wreorder (init order) and -Wsign-compare warnings
    [CroasterCommandHandler.cpp]
